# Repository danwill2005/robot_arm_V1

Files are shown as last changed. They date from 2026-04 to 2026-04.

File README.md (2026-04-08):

# 6-DOF Modular Robotic Arm: Bare-Metal Control

A 6-axis robotic arm prototyped in cardboard, designed in Siemens NX/Fusion 360, laser-cut from plywood and acrylic, and controlled via register-level programming on the ATmega328P (Arduino Uno).

## Mechanical Design & Iteration
The physical structure was developed through a multi-stage prototyping process:

1. **Low-Fidelity Prototyping:** Constructed an initial model using cardboard sheets to validate the 6-Degrees of Freedom (DOF) mechanics and joint ranges.
2. **CAD Modeling (Siemens NX):** Developed a 3D assembly in Siemens NX to define the structural layout and pivot points.
3. **Refinement & Export (Autodesk Fusion):** Transitioned the design to Fusion 360 to refine individual components and export precise 2D sketches for manufacturing.
4. **Manufacturing & Assembly:** * **Chassis:** Laser-cut from 3mm Plywood for an optimal strength-to-weight ratio.
    * **Claw/Gripper:** Laser-cut from 3mm Acrylic. Acrylic was chosen over plywood for the end-effector to ensure smoother gear engagement and higher precision in the gripping mechanism.
    * **Modular Design:** The arm is built with a modular philosophy, allowing individual segments or servos to be swapped out for maintenance or upgrades.

## Hardware Stack
* **Microcontroller:** Arduino Uno (ATmega328P)
* **Actuators:** 6x SG90 Micro Servos
* **Power Supply:** WSP3010H Bench Power Supply
* **Materials:** 3mm Plywood, 3mm Acrylic, M3 screws and nuts

## Firmware & Electronics
The control system is built using a Bare-Metal C++ approach, interacting directly with the ATmega328P hardware registers.]

## Control Goals
 **6 Working Servos with preprogrammed sequence**
 **Inverse Kinematics implemntation to reach pre-programmed positions**

##  Repository Structure
* `/src`: Contains the `.cpp` and `.h` files featuring register-level setup and ISR logic.
* `/cad`: Includes exported DXF files for laser cutting and 3D assembly references.

## Roadmap
* **Iteration 2:** Re-design to be 3D printed and with higher torque MG996R servos. Integration of a potentiometer twin that can be used to control the arm and set a path that can be repeated. Potential implementation of computer vision.
* **Iteration 3:** 3D printed design using stepper motors rather than servos to improve precison and smooth movement.

## Preview






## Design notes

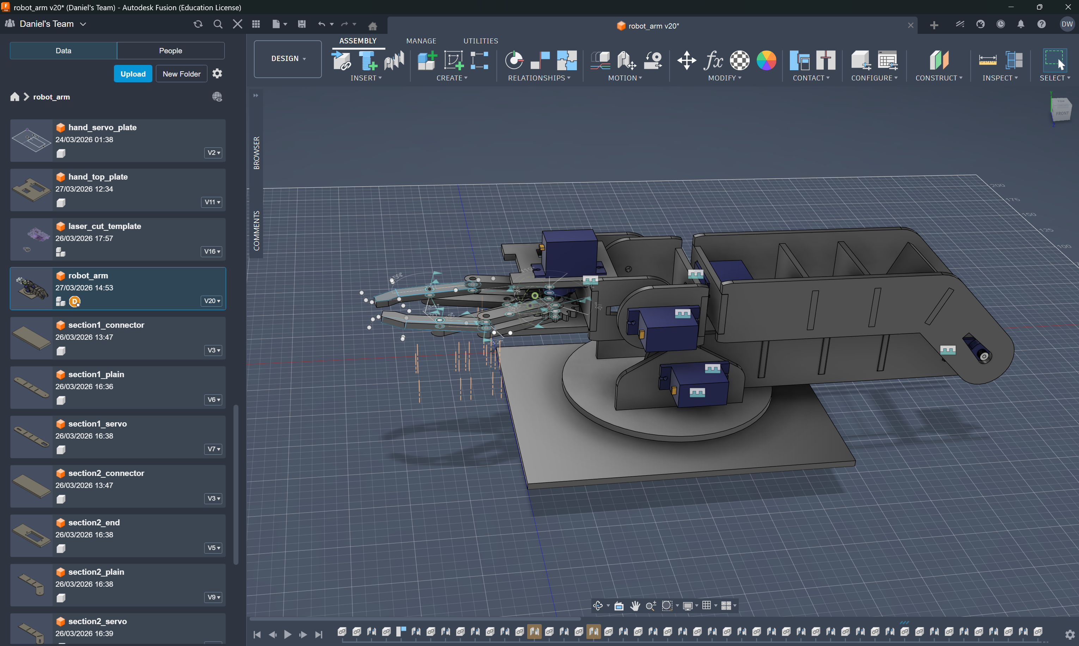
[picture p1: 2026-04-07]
CAD Files/Fusion_360_Final_Design.png

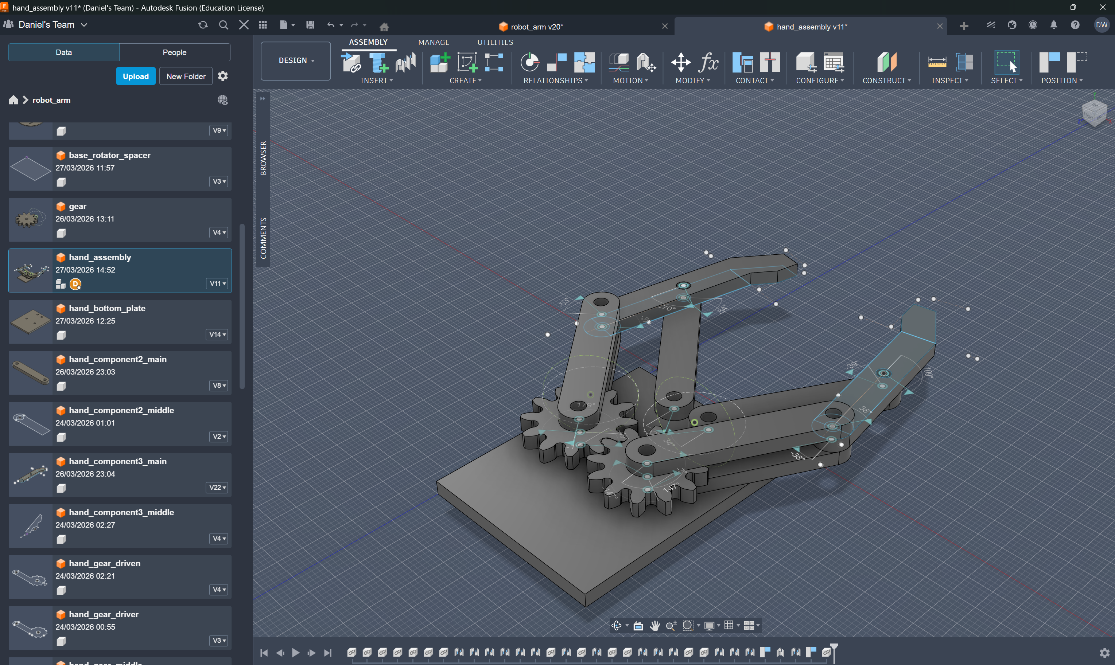
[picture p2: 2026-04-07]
CAD Files/Final_Claw_Design.png

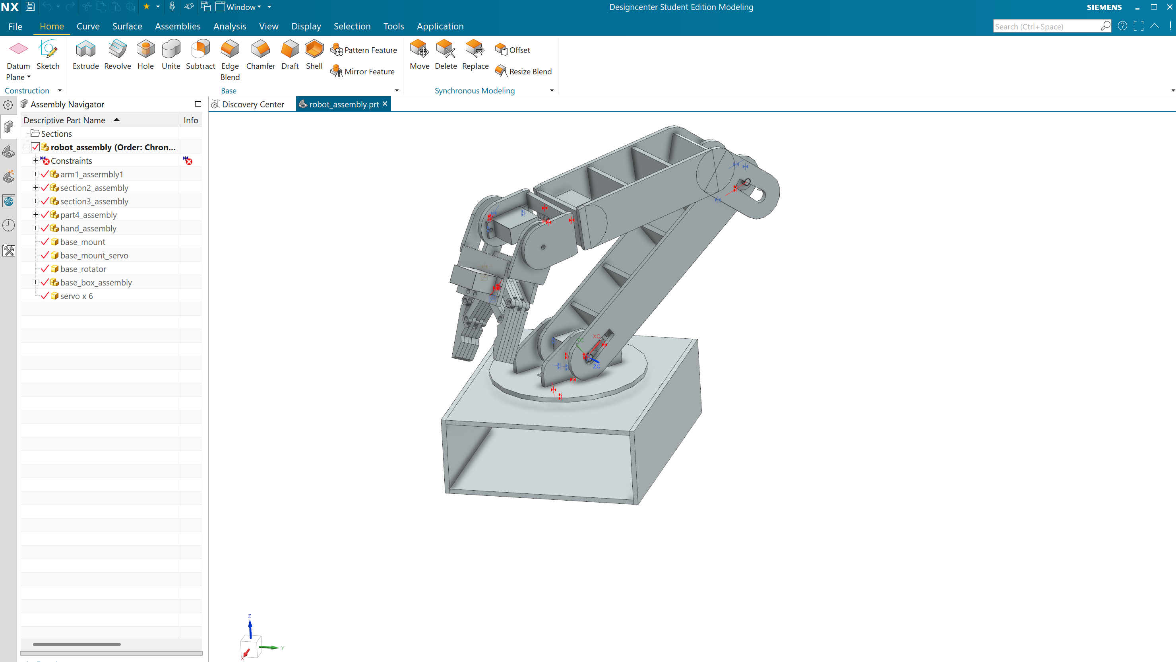
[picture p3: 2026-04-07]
CAD Files/Siemens_NX_initial_design.png

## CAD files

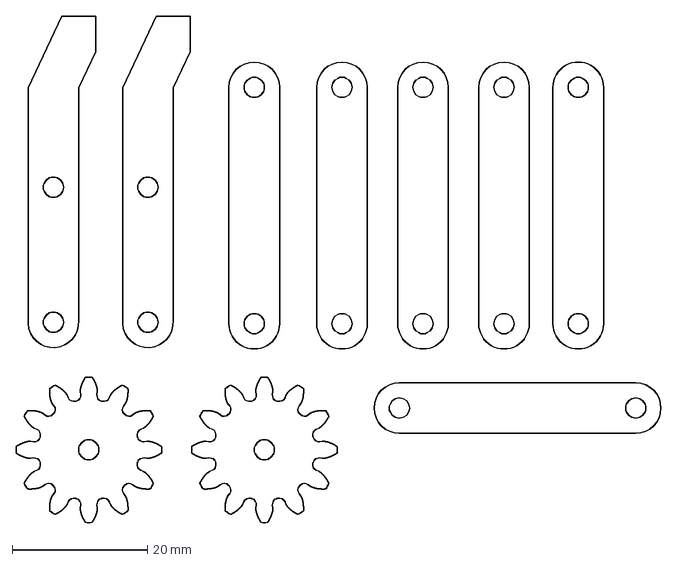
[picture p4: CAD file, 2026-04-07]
CAD Files/acrylic_lasercutting.dxf
95.5 x 75.0 mm

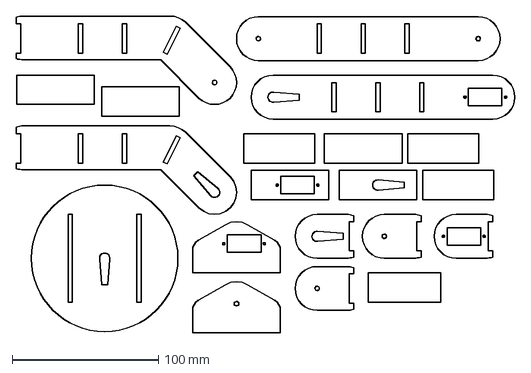
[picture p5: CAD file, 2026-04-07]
CAD Files/daniel_w_robot_arm.dxf
340.4 x 216.4 mm

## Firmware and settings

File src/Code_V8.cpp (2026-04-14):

/*
 * robot_arm.cpp
 *
 * Created: 09/04/2026
 * Author : Daniel Williams
 */ 


#include <avr/io.h>
#include <util/delay.h>
#include <avr/interrupt.h>
#include <util/atomic.h>
#include <stdlib.h>

//these will be the tick values that equate to the ms value of the pulse width that determines a specific angle, servos have range 0.5-2.5ms --> 1000 - 4500 ticks
volatile uint16_t servo1_angle = 3000;
volatile uint16_t servo2_angle = 1000;
volatile uint16_t servo3_angle = 4500;
volatile uint16_t servo4_angle = 3000;
volatile uint16_t servo5_angle = 3000;
volatile uint16_t servo6_angle = 3000;

void uart_init() {
    UBRR0H = 0;
    UBRR0L = 103; // 9600 baud for 16MHz clock
    UCSR0B = (1 << RXEN0); // Enable Receiver
    UCSR0C = (1 << UCSZ01) | (1 << UCSZ00); // 8-bit data, 1 stop bit
}

char uart_receive() {
    while (!(UCSR0A & (1 << RXC0))); // Wait for data
    return UDR0;
}

void process_serial() {
    if (UCSR0A & (1 << RXC0)) { // Is there a character waiting?
        char c = UDR0;
        
        if (c == '<') { // Start of packet
            char buffer[10];
            uint8_t i = 0;
            
            // Read until end of packet or buffer full
            while (i < 9) {
                char next = uart_receive();
                if (next == '>') break;
                buffer[i++] = next;
            }
            buffer[i] = '\0'; // Null terminator to make it a string

            // buffer now looks like "S1:3450"
            uint16_t new_angle = atoi(&buffer[3]); // Convert "3450" to integer
			//printf("%d", new_angle);
            // Update the correct servo
			// Inside process_serial() after atoi...
			ATOMIC_BLOCK(ATOMIC_RESTORESTATE) {
				switch(buffer[1]) {
					case '1': servo1_angle = new_angle; break;
					case '2': servo2_angle = new_angle; break;
					case '3': servo3_angle = new_angle; break;
					case '4': servo4_angle = new_angle; break;
					case '5': servo5_angle = new_angle; break;
					case '6': servo6_angle = new_angle; break;
				}
			}
        }
    }
}

//This function sets up the registers in Timer 1 (16 bit) for Normal port and counter operation
void setup_pwm(){
	
	//TCCR1A register set to Normal port and clock operation
	TCCR1A = 0x00;
	
	//sets prescalar to 8
	TCCR1B = (1<<CS11);
	
	//Enables interrupt for TIMER1_COMPA
	TIMSK1 = (1<<OCIE1A); 
	
	//initialise OCR1A
	OCR1A = 0;
	
	//Enable global interrupts
	sei();
}


void setup_ports(){
	//sets pins 5,6,7 to output
	DDRD |= (1<<DDD5) | (1<<DDD6) | (1<<DDD4);
	
	//sets pins 8,9,9 to output
	DDRB |= (1<<DDB0) | (1<<DDB1) | (1<<DDB2);
	
}

//cycle stage for the switch case, allows for a series of pulses within the 20ms window
volatile uint8_t cycle_stage = 0;



ISR(TIMER1_COMPA_vect){
	
	switch(cycle_stage){
		//start of 20ms cycle
		//want to set the pulse of servo 1
		case 0:
			PORTD |= (1<<PORTD5);//sets pin 5 to HIGH
			OCR1A += servo1_angle; // sets the next interrupt to be the end of servo 1 pulse width
			cycle_stage = 1;
		break;
		//turn off servo1 and wait until the end of the 2.5ms slot
		case 1:
			PORTD &= ~(1<<PORTD5);//pin 5 LOW
			OCR1A += (4500-servo1_angle);// gives servo 1 a 2.5ms slot
			cycle_stage = 2;
		break;
		//turn on servo 2
		case 2:
			PORTD |= (1<<PORTD6);//pin 6 HIGH
			OCR1A += servo2_angle; //sets the next interrupt to be the end of servo 2 pulse width
			cycle_stage = 3;			
		break;
		//turn off servo2 pulse and wait until end of 2.5ms slot
		case 3:
			PORTD &= ~(1<<PORTD6);//pin 6 LOW
			OCR1A += (4500-servo2_angle);// gives servo 2 a 2.5ms slot
			cycle_stage = 4;	
		break;
		//turn on servo 3
		case 4:
			PORTD |= (1<<PORTD4);//pin 7 HIGH
			OCR1A += servo3_angle; //sets the next interrupt to be the end of servo 3 pulse width
			cycle_stage = 5;
		break;		
		//turn off servo3 pulse and wait until end of 2.5ms slot
		case 5:
			PORTD &= ~(1<<PORTD4);//pin 7 LOW
			OCR1A += (4500-servo3_angle);// gives servo 3 a 2.5ms slot
			cycle_stage = 6;
		break;
		//turn on servo 4
		case 6:
			PORTB |= (1<<PORTB0);//pin 8 HIGH
			OCR1A += servo4_angle; //sets the next interrupt to be the end of servo 4 pulse width
			cycle_stage = 7;
		break;
		//turn off servo4 pulse and wait until end of 2.5ms slot
		case 7:
			PORTB &= ~(1<<PORTB0);//pin 8 LOW
			OCR1A += (4500-servo4_angle);// gives servo 4 a 2.5ms slot
			cycle_stage = 8;
		break;
		//turn on servo 5
		case 8:
			PORTB |= (1<<PORTB1);//pin 9 HIGH
			OCR1A += servo5_angle; //sets the next interrupt to be the end of servo 5 pulse width
			cycle_stage = 9;
		break;
		//turn off servo5 pulse and wait until end of 2.5ms slot
		case 9:
			PORTB &= ~(1<<PORTB1);//pin 9 LOW
			OCR1A += (4500-servo5_angle);// gives servo 5 a 2.5ms slot
			cycle_stage = 10;
		break;
		//turn on servo 6
		case 10:
			PORTB |= (1<<PORTB2);//pin 10 HIGH
			OCR1A += servo6_angle; //sets the next interrupt to be the end of servo 6 pulse width
			cycle_stage = 11;
		break;
		//turn off servo6 and wait until the end off 20ms cycle
		case 11:
			PORTB &= ~(1<<PORTB2);//pin 10 LOW
			
			//40000 ticks = 20ms, 16MHz/8 = 2MHz, 0.02/(1/2000000) = 40000;
			OCR1A += (40000-30000);//30000 is the sum of 6*4500 tick slots for the servos
			cycle_stage = 0;
			break;
	}
}

void sweep_to_180_degrees(volatile uint16_t *servo_x_angle){
	uint16_t current_value;
	
	ATOMIC_BLOCK(ATOMIC_RESTORESTATE){
		current_value = *servo_x_angle;//prevents interrupt during reading of the while loops in the function
	}
	
	while(current_value < 5000){ //rotates to 180 degrees
			ATOMIC_BLOCK(ATOMIC_RESTORESTATE){//prevents interrupt during reading 16 bit integer
				*servo_x_angle+=75;// =~ 3degree steps
				current_value = *servo_x_angle;
			}
			_delay_ms(20); //allows for slower movement
	}	
	
	ATOMIC_BLOCK(ATOMIC_RESTORESTATE){
		*servo_x_angle = 5000;
	}
}

void sweep_to_0_degrees(volatile uint16_t *servo_x_angle){
	
	uint16_t current_value;
	
	ATOMIC_BLOCK(ATOMIC_RESTORESTATE){
		current_value = *servo_x_angle;//prevents interrupt during reading of the while loops in the function
	}
	
	while(current_value > 1000){ //rotates to 0 degrees
			ATOMIC_BLOCK(ATOMIC_RESTORESTATE){//prevents interrupt during reading 16 bit integer
				*servo_x_angle-=75;// =~ 3degree steps
				current_value = *servo_x_angle;
			}
			_delay_ms(20); //allows for slower movement
	}
	
	ATOMIC_BLOCK(ATOMIC_RESTORESTATE){
		*servo_x_angle = 1000;
	}
}

void sweep_to_90_degrees(volatile uint16_t *servo_x_angle){
	
	uint16_t current_value;
	
	ATOMIC_BLOCK(ATOMIC_RESTORESTATE){
		current_value = *servo_x_angle;//prevents interrupt during reading of the while loops in the function
	}
	
	while((current_value > 3075) || (current_value < 2925)){ //rotates to 180 degrees
		if(current_value < 2925){
			ATOMIC_BLOCK(ATOMIC_RESTORESTATE){//prevents interrupt during reading 16 bit integer
				*servo_x_angle+=75;// =~ 3degree steps
				current_value = *servo_x_angle;
			}
			_delay_ms(20); //allows for slower movement
		}else if(current_value > 3075){
			ATOMIC_BLOCK(ATOMIC_RESTORESTATE){//prevents interrupt during reading 16 bit integer
				*servo_x_angle-=75;// =~ 3degree steps
				current_value = *servo_x_angle;
			}		
			_delay_ms(20);	
		}
	}
	
	ATOMIC_BLOCK(ATOMIC_RESTORESTATE){
		*servo_x_angle = 3000;
	}

}

void servo_x_startup(volatile uint16_t *servo_x_angle){
	//startup function for each servo
	//goes to 180 deg, then to 0, then to 90
	
	sweep_to_180_degrees(servo_x_angle);
			
	_delay_ms(1000);
			
	sweep_to_0_degrees(servo_x_angle);
			
	_delay_ms(1000);
			
	sweep_to_90_degrees(servo_x_angle);
	
}

uint8_t move_by_step_until_target(volatile uint16_t *servo_x_angle, uint16_t target){
	
	uint16_t current_value;
	
	ATOMIC_BLOCK(ATOMIC_RESTORESTATE){
		current_value = *servo_x_angle;
	}
	
	if(current_value < (target - 75)){
		ATOMIC_BLOCK(ATOMIC_RESTORESTATE){
			*servo_x_angle += 75;
		}
		return 1;
	}
	else if (current_value > (target + 75)){
		ATOMIC_BLOCK(ATOMIC_RESTORESTATE){
			*servo_x_angle -= 75;
		}
		return 1;
	}
	else{
		ATOMIC_BLOCK(ATOMIC_RESTORESTATE){
			*servo_x_angle = target;
		}
		return 0;
	}
	
}

void simultaneous_movement(){// to test maximum current draw
	// move all servos to 180 degrees
	while (move_by_step_until_target(&servo1_angle, 5000) | move_by_step_until_target(&servo2_angle, 5000) | move_by_step_until_target(&servo3_angle, 5000) | move_by_step_until_target(&servo4_angle, 5000) | move_by_step_until_target(&servo5_angle, 5000) | move_by_step_until_target(&servo6_angle, 5000))
	{
		_delay_ms(20);
	}

	_delay_ms(1000);

	// move all servos to 0 degrees
	while (move_by_step_until_target(&servo1_angle, 1000) | move_by_step_until_target(&servo2_angle, 1000) | move_by_step_until_target(&servo3_angle, 1000) | move_by_step_until_target(&servo4_angle, 1000) | move_by_step_until_target(&servo5_angle, 1000) | move_by_step_until_target(&servo6_angle, 1000))
	{
		_delay_ms(20);
	}	
	
	//move all servos to 90 degrees
	while (move_by_step_until_target(&servo1_angle, 3000) | move_by_step_until_target(&servo2_angle, 3000) | move_by_step_until_target(&servo3_angle, 3000) | move_by_step_until_target(&servo4_angle, 3000) | move_by_step_until_target(&servo5_angle, 3000) | move_by_step_until_target(&servo6_angle, 3000))
	{
		_delay_ms(20);
	}	
}

int main(void) {
	//position the robot to be in the 90 degrees rest position to prevent startup jerk
	setup_ports();
	uart_init();
	setup_pwm();

	servo_x_startup(&servo1_angle);
		_delay_ms(1000);
	servo_x_startup(&servo2_angle);
		_delay_ms(1000);
	servo_x_startup(&servo3_angle);
		_delay_ms(1000);
	servo_x_startup(&servo4_angle);
		_delay_ms(1000);
	servo_x_startup(&servo5_angle);
		_delay_ms(1000);
	servo_x_startup(&servo6_angle);
		_delay_ms(1000);

	simultaneous_movement();

	while(1) {
		// If the buffer is overflowing with junk, clear it
		if (UCSR0A & (1 << DOR0)) {
			uint8_t dummy = UDR0; 
		}
		process_serial();
	}
}

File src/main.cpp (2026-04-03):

/*
 * robot_arm.cpp
 *
 * Created: 29/03/2026 23:27:12
 * Author : Lenovo
 */ 

#include <avr/io.h>
#include <util/delay.h>
#include <avr/interrupt.h>

void setup_servo_pwm() {
	//Set pin 9 and 10 as output
	DDRB |= (1 << DDB1) | (1 << DDB2);

	//Configure Timer 1 for Fast PWM mode (Mode 14)

	//COM1A1 clears OC1A on Compare Match (non-inverting)
	TCCR1A = (1 << COM1A1) | (1<<COM1B1) | (1 << WGM11);
	TCCR1B = (1 << WGM13) | (1 << WGM12) | (1 << CS11); // Prescaler = 8

	//ICR1 defines the TOP value (the 20ms period)
	//Formula: (F_CPU / (Prescaler * Frequency)) - 1
	//(16,000,000 / (8 * 50)) - 1 = 39,999
	ICR1 = 39999;
	
	//starting angles for servo 1 and 2
	OCR1A = 3000;
	OCR1B = 1100;
}




void setup_software_pwm(){
	//Set pin 11 as output for servo 3
	DDRB |= (1 << DDB3);
	
	//Set timer 2 to CTC mode
	TCCR2A = (1 << WGM21);
	
	//Enable the Interrupt
	TIMSK2 |= (1 << OCIE2A);
	
	//Set Prescaler to 1024
	TCCR2B = (1 << CS22) | (1<< CS21) | (1<<CS20);
	
	OCR2A  = 31;
	
	sei(); // Enable Global Interrupts
}

volatile uint16_t cycle_stage  = 0; //keeps track of current postion in the 20ms cycle
volatile uint16_t servo_value3 = 31; //1.5ms 1500/64us (1/16MHz/1024)

ISR(TIMER2_COMPA_vect) {
	//on the first interrupt this code will run
if (cycle_stage == 0) {
	//start of pulse
	PORTB |= (1 << PORTB3); // Pin HIGH
	
	// Schedule the end of pulse interrupt
	// new compare value = current count (starting 0) + desired angle ticks
	OCR2A = servo_value3;
	
	//set next stage of PWM cycle
	cycle_stage = 1;
}
//on the second interrupt with the new compare value this code will run
else if (cycle_stage == 1) {
	//end of pulse
	PORTB &= ~(1 << PORTB3); // Pin LOW
	
	// Schedule the start of next cycle (20ms later)
	// 20ms / 64us = 312 ticks.
	// already used 23 ticks, wait 289 more.
	// Timer 2 only goes to 255, handle the overflow here:
	OCR2A = 150; // Wait halfway through the 20ms
	cycle_stage = 2;
}
//this runs on the third interrupt
else {
	// reset for next pulse cycle
	OCR2A = (162-servo_value3);
	cycle_stage = 0;
	}
}

void servo1_startup(){
	//sweeps to 180deg
	while(OCR1A < 5000){
		OCR1A += 50;
		_delay_ms(20);
	}
	
	_delay_ms(500);
	
	//sweeps to 0 deg
	while(OCR1A > 1000){
		OCR1A -= 50;
		_delay_ms(20);
	}
	_delay_ms(500);
	//sweeps to 90deg
	while(OCR1A < 3000){
		OCR1A += 50;
		_delay_ms(20);
	}
	OCR1A =3000;
}

void servo2_startup(){
	//sweeps to 180
		while(OCR1B < 4900){
			OCR1B += 75;
			_delay_ms(20);
		}
		
		_delay_ms(500);
		//sweeps to 90
		while(OCR1B < 3000){
			OCR1B += 75;
			_delay_ms(20);
		}
		
		_delay_ms(500);		
//sweeps to 0
		while(OCR1B > 1100){
			OCR1B -= 75;
			_delay_ms(20);
		}


		OCR1B =1100;
	
}

void servo3_startup(){
	
	//sweeps to 180
	while(servo_value3 < 39){
		servo_value3 += 1;
		_delay_ms(50);
	}
	//0deg
	while(servo_value3 > 10){
			servo_value3 -= 1;
			_delay_ms(50);
	}
	//90deg
	while(servo_value3 < 31){
		servo_value3 += 1;
		_delay_ms(50);
	}
	servo_value3 = 31;
}

int main(void) {
	setup_servo_pwm();
	//setup_software_pwm();
	
_delay_ms(1000);
servo1_startup();
_delay_ms(1000);
servo2_startup();
_delay_ms(1000);
//servo3_startup();

//both servos move at the same time
while ((OCR1A != 5000) || (OCR1B != 3000)){
	//move to target angle
	if (OCR1A < 5000){
		OCR1A += 75;		
	}//prevent overshoot due to ||
	if(OCR1A >= 5000){
		OCR1A = 5000;
	}
	if (OCR1B < 3000){
		OCR1B += 75;
	}
	if(OCR1B >= 3000){
		OCR1B = 3000;
	}
	_delay_ms(20);
}
_delay_ms(1000);

//return to inital position to rpevent snap on next upload
while ((OCR1A > 3000) || (OCR1B > 1100)){
	OCR1A -= 75;
	OCR1B -= 75;
	_delay_ms(20);
}

OCR1A = 3000;
OCR1B = 1100;

	while(1){
		
	}
}

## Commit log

2026-04-02 Current robot arm servo code using bare metal approach 03/04/2026
    I have ran into an issue where the servos become jittery when i plug in 3 vs only using 2. I initially thought it was a hardware issue and limitation of breadboard wires however I re-wrote the code in arduino IDE using servo.h library and the issue was solved. This tells me that my current timer setup is inefficient to needs revisions
2026-04-03 Changed software pwm code
    I changed the interrupts from being every 50us to only at the start and end of the pulse and halfway through the total 20ms cycle. I only have the 8 bit timers left so the precision is low but this reduced the jitter from the other two servos as the CPU overhead is lower. This code only runs two servos as it was meant for the base, shoulder and elbow but the elbow and shoulder are not strong enough to raise the whole are so i detached the arm from the elbow so only the base and upper arm move. The bottom half of the code demonstrates that both servos can move simultaneously without losing smoothness.
    [main.cpp]
2026-04-07 Add the remaining servos to the software PWM
    I have used bitmasking to efficiently add the remaining servos to the software PWM however i am currently using parallel PWM so all of the servos share the same movement. My next step is to implement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
2026-04-07 Design_Files
    This upload contains the final laser cut files that became the robot arm V1. This cam after 2 iterations with the second having altered dimension to make assembly and integration of the servos easier, as well as a redesigned claw mechanism to be laser cut from acrylic rather than wood as was planned initially. This upload also contains screenshots of the initial robot CAD design in Siemens NX and the redesign in Fusion 360 where dxf files could be exported.
    [acrylic_lasercutting.dxf, daniel_w_robot_arm.dxf]
2026-04-07 Series PWM signal
    This code changes the software PWM from parallel PWM to series PWM, allowing all of the servos on the 8 bit timer to have independent movement. The code implemets startup sequences for each servo and demonstrates that all can move simultaneously without losing strength. There is still clear jitter issues due to the lack of precision from the 8 bit timer. Therefore the next iteration will use the 16 bit timer for series PWM signals using normal mode rather than CTC
    [Code_V4.cpp]
2026-04-07 All put together
    This code demonstrates that the arm works with all of the servos running using 2 Fast PWM signals on a 16bit timer and 3 interrupt signals on an 8 bit timer.
2026-04-07 Remove wiring schematics section from README
    Removed the documentation section for wiring schematics and register mapping tables.
2026-04-11 switching to 16 bit timer, interrupt oriented PWM signal
    This code uses the 16 bit timer to generate PWM signals for all 6 servos. The code interrupts at the start and end of each pulse as well as the end of the 20 ms cycle. each servo is given a 2.5ms "slot" even if the angle is not 180 degrees(like 1.5ms) as this prevents the start of the next signal being dependent on the end of the last one. ATOMIC_BLOCK has been used when 16 bit integers are re-assigned values to prevent an interrupt during the reading of the 2 bytes. The next steps for this code are to atomise the functions, i.e. make seperate function for moving to 5000, 1000, 3000 rather than all 3 in one startup, as well as using po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
    [Code_V6.cpp]
2026-04-12 Atomised functions
    This code atomises a lot of the functions in previous iterations, for example moving to 180, 0, 90 degrees are all their own function and have pointers passed to them for the respective servo, then t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
2026-04-14 Add GUI for 6-Axis Robot Controller with sliders
    This code uses python to create a GUI that has 6 sliders that control each servo. I t sends packets containing a servo identifier and the desired angle over UART to the arduino. This will probably be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
2026-04-14 Add control through GUI
    This code sets up UART communication between python code and the movement code. Had issues with the servos not moving despite data being sent and the issue was the baud rate was too high. This is the final code upload for this project as i will now move onto Version 2 of the arm.
    [Code_V8.cpp]
